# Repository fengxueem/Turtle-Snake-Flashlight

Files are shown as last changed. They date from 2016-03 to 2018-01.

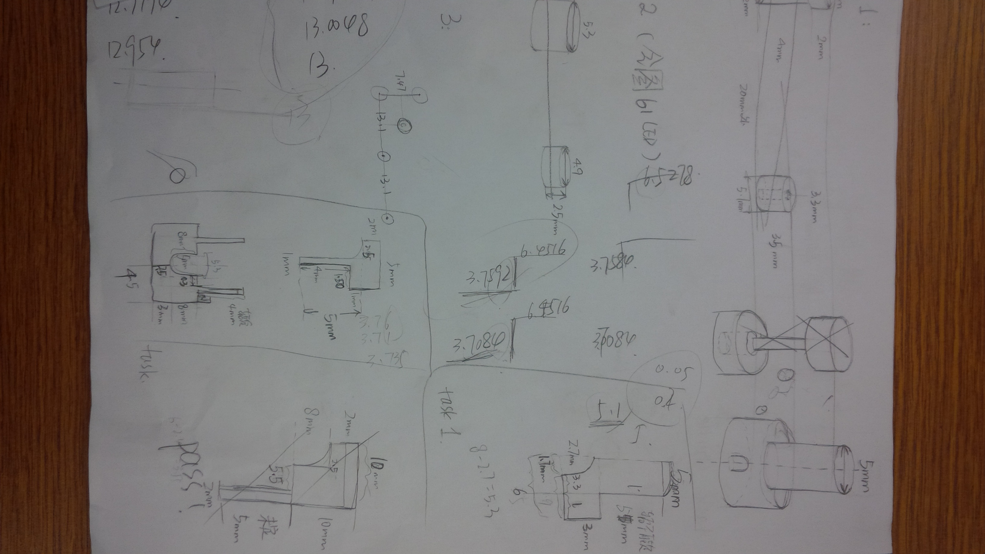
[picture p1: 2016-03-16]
Documents for EXPO2015/early sketch/Button design 2.jpg

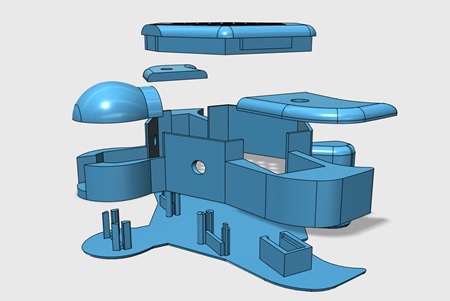
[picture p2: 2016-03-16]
Documents for EXPO2015/123dx/turtle-assemble.jpg

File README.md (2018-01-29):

# Turtle-Snake-Flashlight
This is group work as a senior design project of UIC. We created a turtle-shaped flashlight where user can play the classic "Snake Game" from stratch. This repository contains everything we've done to make it happen.
If this triggers any interests, feel free to contact me at fengxueem@sina.com

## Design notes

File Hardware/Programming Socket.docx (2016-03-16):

Programming Socket

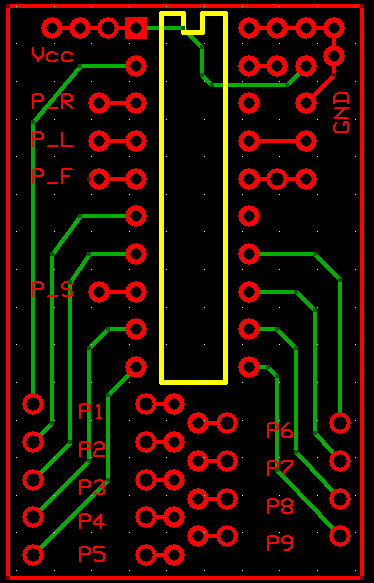
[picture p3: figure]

Programming socket

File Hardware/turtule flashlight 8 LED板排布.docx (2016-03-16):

FlaLED

FlaLED

FlaLED

FlaLED

100

100

100

Vcc

GND

100

C B E

10k

GND

10k

FlaLED

GND

C B E

FlaLED

100

100

FlaLED

FlaLED

100

100

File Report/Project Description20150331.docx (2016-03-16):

Date: 03/31/2015

Senior design project: turtle

Theme: summary on the progress so far

1. Programmable Flashlight: we decided to use hexagon as main body at very beginning which is also the shape of upper shell of the turtle. Hence, our idea changes from hexagon to make a turtle. As an extra feature for this flashlight is asked and we have a large body filled with LEDs which is perfectly for a game screen, we embed the famous and classic "Snake Game" inside.
2. Flashlight LED: The basic function of our product is flashlight. Hence, we put 8 small LEDs in the front of turtle head to illuminate everything ahead as a normal flashlight does. All the flashlights are driven by the battery with a transistor working as their switch that is controlled by an output pin from MSP430G2452.
3. Main body LED matrix: Though the screen made of LEDs is an interesting idea, it's hard for micro-controller to drive large number of LEDs and give each of them coordinates. With the help of our instructor, Vladimir Goncharoff, we use a technique invented by Charlie Allen in 1995, Charlieplexing, to drive 61 LEDs only using 9 I/O pins of MSP4302452 (this micro-controller is assigned by Dr.Goncharoff).When using Charlieplexing, n drive pins can drive A_n^2 =n^2 −n LEDs with every two pins connecting two LEDs forward and reverse.

Thus 9 pins are able to control 72 LEDs, and we only make use of 61 LEDs of total 72 possible LEDs arranged in shape of hexagon consisting of 9 columns and 9 lines. If we need to light one specific LED, the only thing we need to do is output a high voltage at its anode and low voltage at cathode, which is assigned with coordinates we designed especially for this hexagon matrix.

4. User interface: This flashlight has 4 buttons. Three of them are used for snake game and the rest one is for flashlight. The game buttons are: left button (make the snake turn left), right button (make the snake turn right) and game power switch (On/Off). The flashlight button turns 8 flashlight LEDs on and off. Normally, the voltage of all four buttons is high pulled up the built-in pull-up resistors. Once the voltage is detected to be low, it means the button is pressed.
5. Snake game: Here is the procedure of our snake game. After player pressing the game power switch, the game will start. A warm-up phase will be the first step to give player enough preparing time. During this phase, the outermost LEDs on the LED matrix will be lighted one by one with a fixed starting LED and the same one as ending LED. When the warm-up phase is finished, a snake and the first target will be shown at the LED matrix with random position and won't move until player presses the left or right button. Now the game officially begins, the snake will follow the direction given by player pressing different button. Once the snake gets a target, the speed of snake will increases and one new target will show up still randomly. As the player gets more and more targets, the speed will increase but won't go beyond a limitation. The game will end only in two situations: 1. the player presses the game power switch to shut it down; 2. the snake hits one of the six edges of our hexagon LED matrix. A feedback of how many targets this player gets will be displayed by means of a snake running from the top LED along the outermost circle to some point which is determined by player's score. The higher score the player gets, the longer the snake runs at feedback. And the player can choose to show his score to other people if he/she doesn't press left or right button after the feedback. If he/she presses, whole game will restart and run from the warm-up phase again.
6. Appearance: The turtle is made up with 6 3D-printed pieces: one top hexagon LED screen case (TOP), one middle supporting body (MID), one bottom base (BAS), two turtle libs (LIB) and one turtle head (HED). Two LIB and one HED are glued on the top surface of the MID. TOP is inserted into MID. And BAS is glued on the bottom surface of the MID.

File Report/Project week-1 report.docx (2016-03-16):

Project Week 1 Report

Group: 2B

(1). Description of the game

We designed a game named “catching star” based on the LEDs. We designed 4 buttons for the product. One is “on/off” button used for turning on and off the game. One is “reset” button used to restarting the game. “Left” and “right” buttons are used for changing the forwarding direction of the snake to left or right in 60 degrees.

After you pressing the “on/off” button, the game will start. You will have a warm-up time. During this period, the LED at the center will light in blue; meanwhile, the lights on the periphery will be lighted one by one with a random starting point. When the circle lighting finished, the end three LEDs will be the snake with the last lighted LED as the head of the snake. The LED at the center would be turned off. And a random LED on the plane will be lighted as the target “star”.

The snake will move forward automatically, you can change the direction of the snake with the “left” and “right” buttons. When you press the “left” (“right”) button, the snake will turn left (right) in 60 degrees. Each time the snake caught a star, another LED will be lighted as the target star and the moving speed of the snake would be increased.

When the speed of the snake is up to a specific value, the snake will move with the specific value. When the snake has caught 20 stars, the difficulty level of the game will be increased. The snake will disappear for one second randomly; you have to control the snake with the memory of the position and the speed of the snake. The LED at the center will be lighted in yellow for 3 seconds in random to be a barrier, if the snake hit the yellow LED, game over; if the snake strike into the periphery wall, game over.

If the snake caught 50 stars, you win the game, the central LED will be lighted in the green; if the snake hit the central barrier or the periphery wall, you loss, the central LED will be lighted in red. You can press “reset” to restart the game or “on/off” to stop playing.

(2).Required elements

element | capacitance | Red LED | RGB LED | wire | R(10K) | R | switch
number | 1 | 70(60+10) | 1 | several | 8(6+2) | 11(10+1) | 4

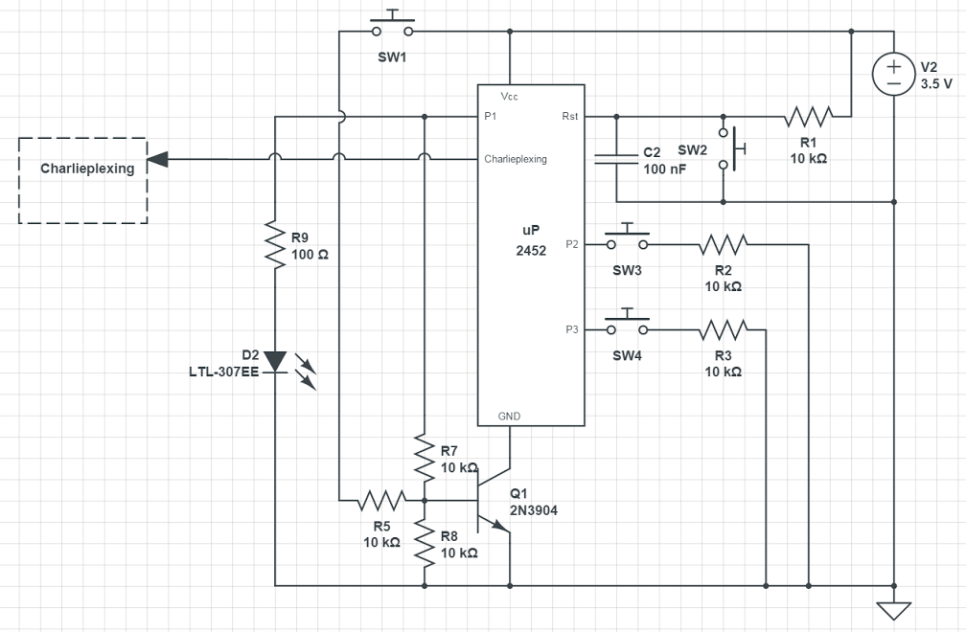
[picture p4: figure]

(3). Circuit

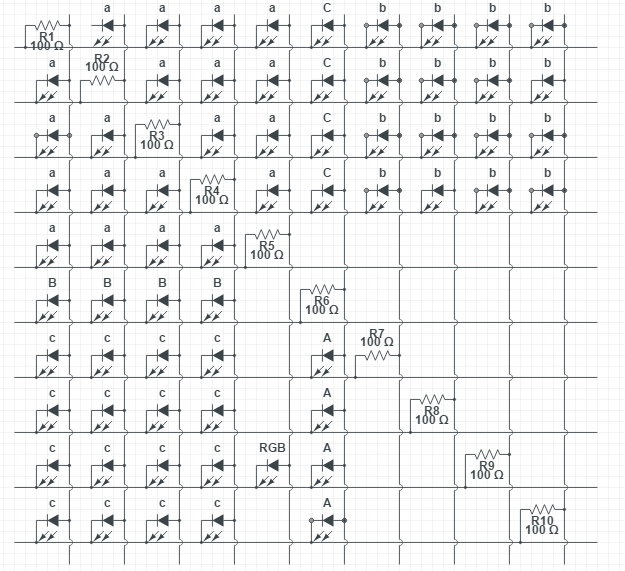
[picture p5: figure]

Charlieplexing circuit

Overall circuit

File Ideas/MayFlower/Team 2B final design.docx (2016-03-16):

Team 2B final design: MayFlower

Our design is a snowflake like flash LED.

- 1. Our product is designed as the shape of regular hexagon. And the hexagon plate is covered with single-color LEDs with one multi-color LED in the center of the hexagon. The “bling bling mode” is designed for decoration. When specific LEDs are lightened, we can get different shapes like snowflakes, sun, umbrella, lightening, characters and so on.

Mode1: different snowflakes will be lightened one by one as a circle.

# Mode2: LEDs could light in 26 characters, different characters are lighted in different order to compose some words like “hi” ”welcome”.

Mode 3: “weather flag”. Choose different weather flags to inform other people about the weather. For example, choose “sun” shinning mode, it means that it’s a sunny today. At the same time, the multi-color LED can light in different colors to mention the temperature. If it’s hot, it will light in red.

- 2. As there are lots of LEDs laying on the hexagon and our design is portable, another function of MayFlower is designed to be "Code Model". We use our LEDs to express some important signals. For instance, we can express SOS by lighting our LEDs three times for 1 second and three times for 0.5 seconds.
- 3. The LEDs can light similar to the appearance of clock. LEDs at the edge of hexagon will light one by one(per second) until LEDs of the first round of hexagon all lighted(per min) Then the second round will lit the same way as first round .This step will keep going if there is still some LEDs unlighted. Once all LEDs are lighted, they will go out together and run the steps above again as a cycle.
- 4. As the regular hexagon is centrosymmetric, we find that our MayFlower can take advantage of this physical property to rotate around the central axis. We can imagine that a rotating LED flashlight is definitely much more attractive than an immobile LED light. To accomplish this idea, we decide to make a smooth hollow rod to be assembled at the center as the rotating axis so that it will not only rotate but also can be easily attached to the wall or some other surface through the hollow part.

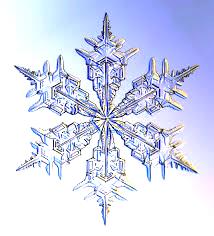
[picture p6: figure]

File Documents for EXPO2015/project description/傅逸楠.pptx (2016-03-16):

## Turtle Snake Flashlight

A teamwork project by JLU&UIC program students:
Jing Li, Chengzhang Li, Bolin Dai and Yinan Fu

Outer case

Reporter: Yinan Fu

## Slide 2

Road map

Project Requirement

Project Vision

Product Presentation

Hardware Design

Outer case Design

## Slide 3

Road map

Project Requirement

Project Vision

Product Presentation

Hardware Design

Outer case Design

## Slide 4

Project Requirement

Topic: Flashlight with one extra function

Limited hardware resources: Micro-controller, LED
(MSP430 from TI)
Resistance, Transistor

Must have a 3D-printed outer case

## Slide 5

Road map

Project Requirement

Project Vision

Product Presentation

Hardware Design

Outer case Design

## Our Vision: Make your flashlight your new snake game player!

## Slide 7

Road map

Project Requirement

Project Vision

Product Presentation

Hardware Design

Outer case Design

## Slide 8

Road map

Project Requirement

Project Vision

Product Presentation

Hardware Design

Outer case Design

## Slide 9

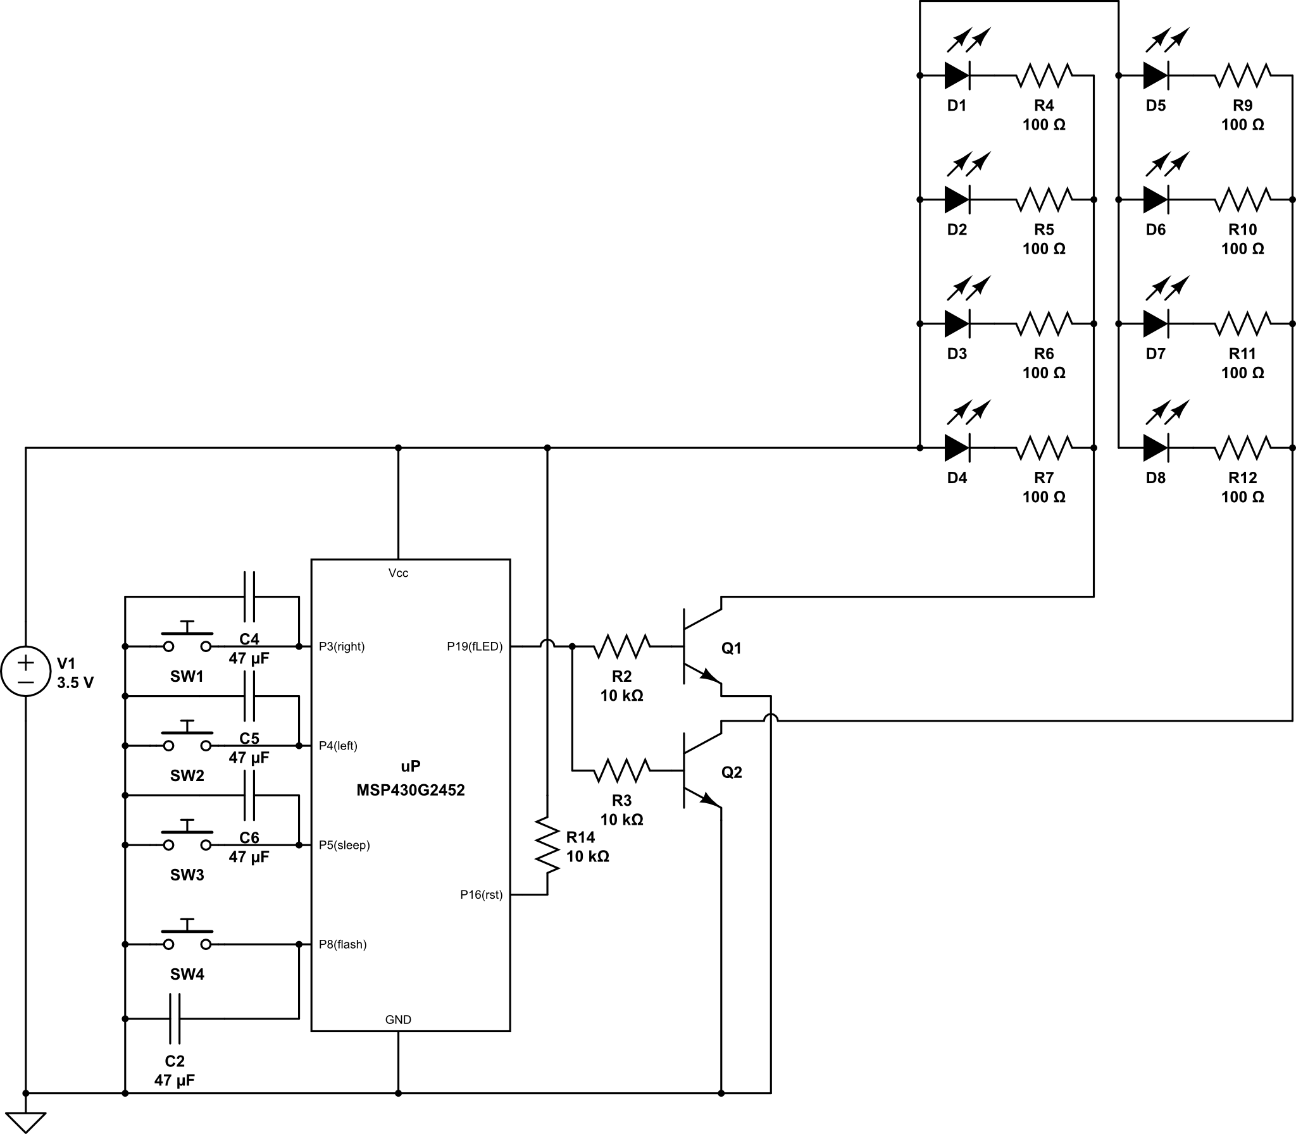
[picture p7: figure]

Main board circuit

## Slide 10

This micro-controller is powered by 3.5 voltage
given by 2 AA batteries.

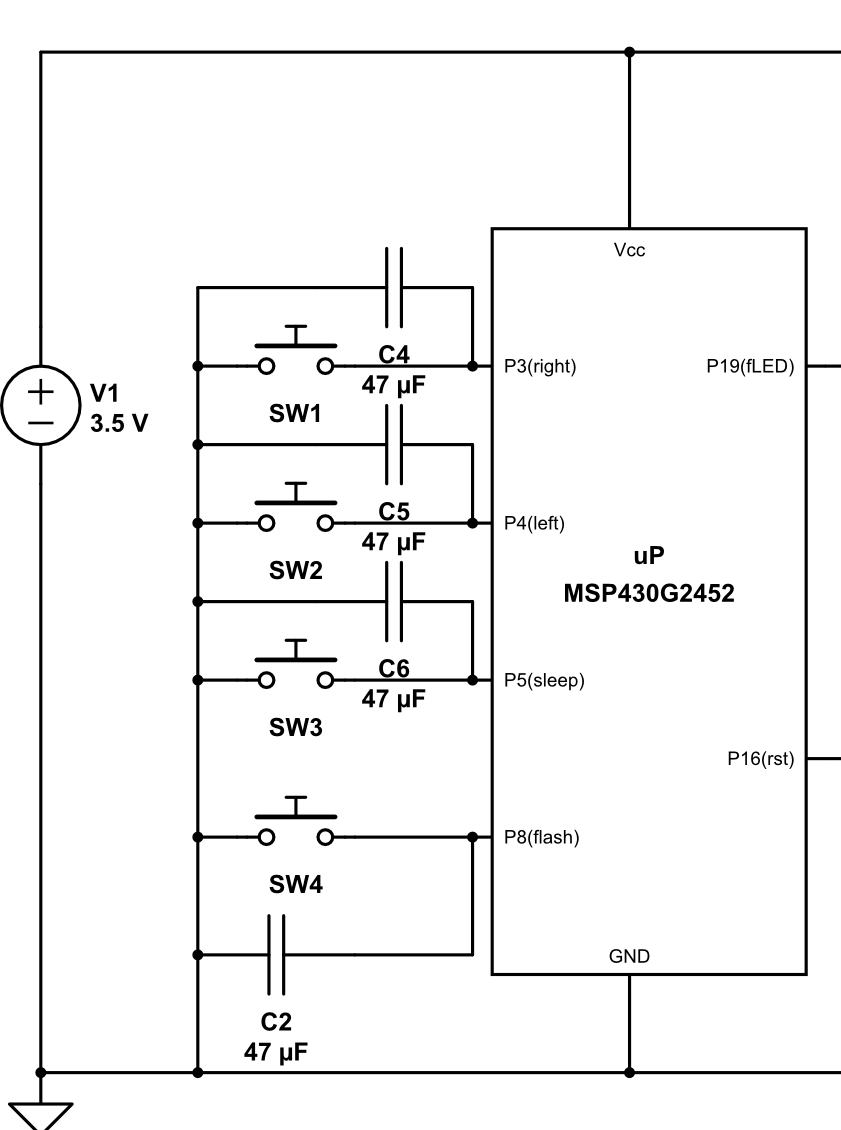
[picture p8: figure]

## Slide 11

Four switches are parallel connected with capacitance
eliminating button bounce and giving a steady press feeling.

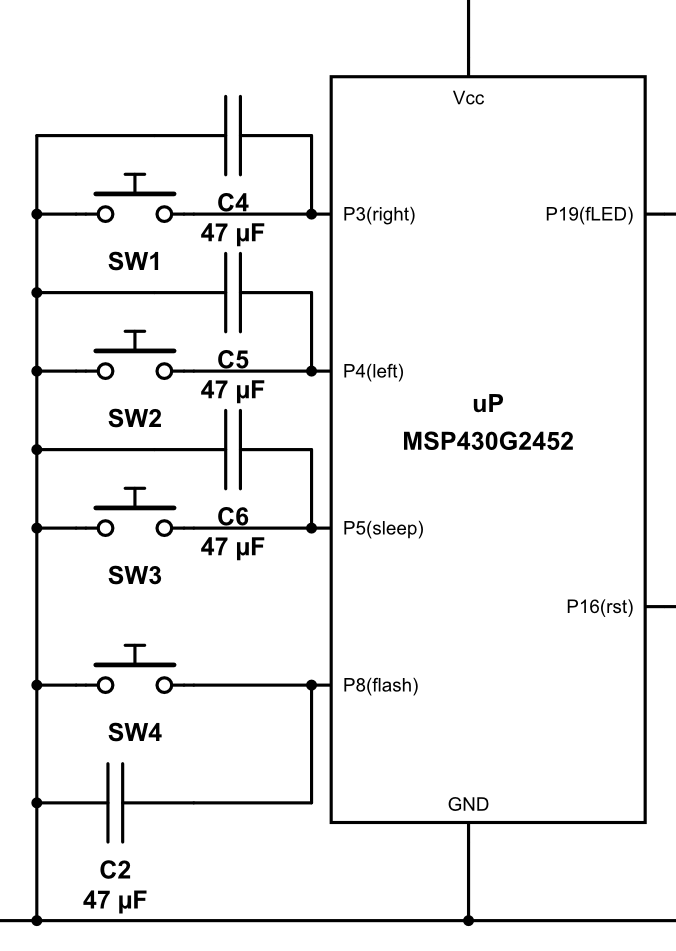
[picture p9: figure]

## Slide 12

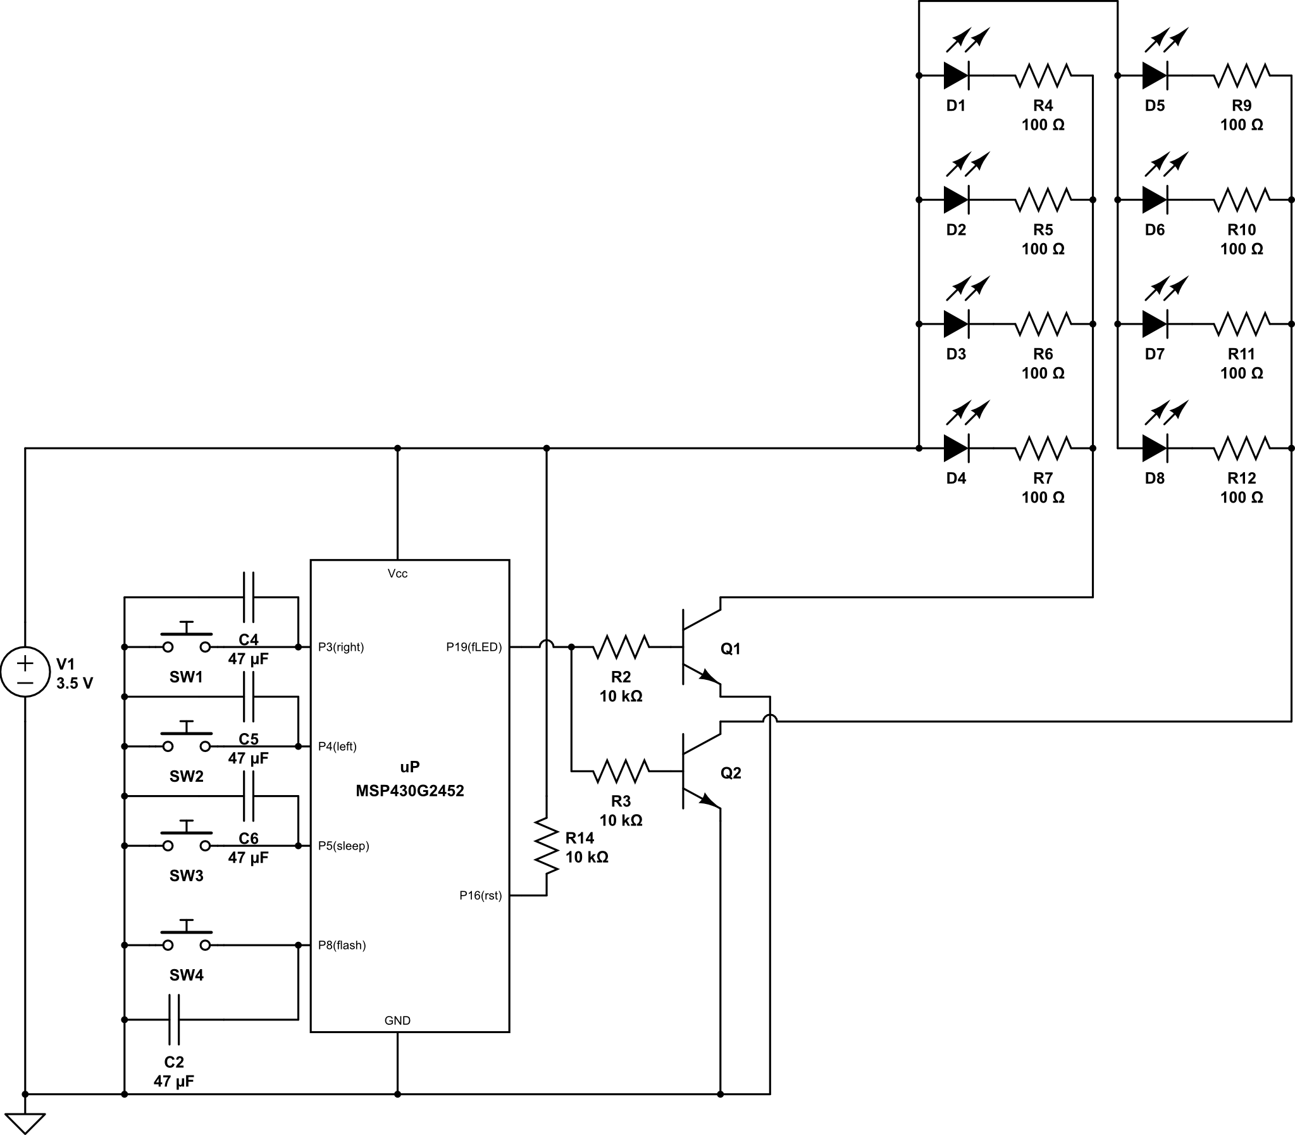
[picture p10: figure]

8 flashlight LEDs are directly driven by the battery.

One I/O pin is used to control the connectivity of these LEDs.

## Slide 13

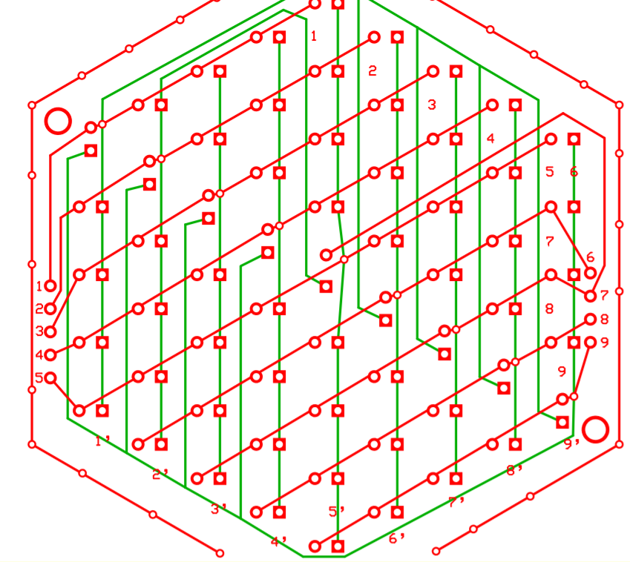
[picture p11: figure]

We use 9 I/O pins to control 61 LEDs

Main LED matrix

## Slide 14

Charlieplexing

P1

2 pins can control 2∗2−2=2 LEDs

P2

P1

P2

3 pins can control 3∗3−3=6 LEDs

P3

n pins can control n∗n−n=n^2 −n LEDs
So, 9 pins are able to have 9∗9−9=72 LEDs,
which is more than enough.

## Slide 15

Road map

Project Requirement

Project Vision

Product Presentation

Hardware Design

Outer case Design

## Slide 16

3D Printer

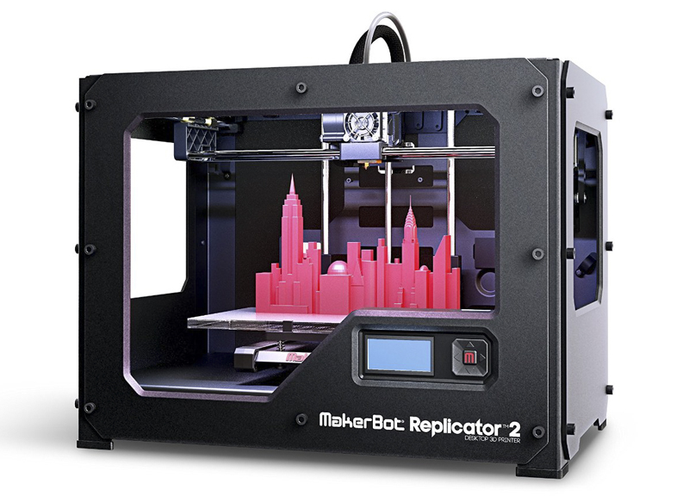
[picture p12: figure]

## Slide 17

Printing Scene

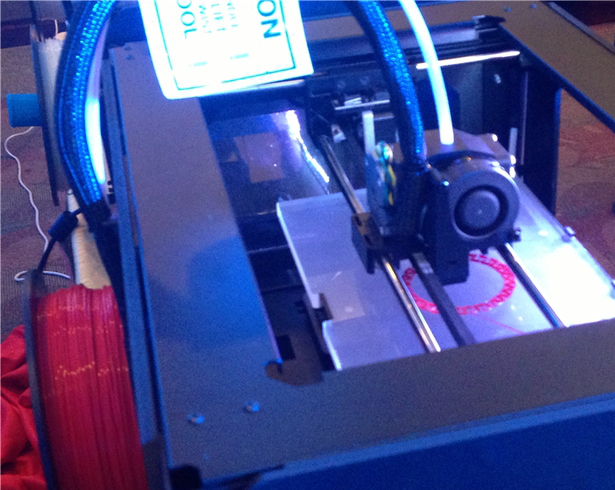
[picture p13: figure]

extruder

filament

Build plane

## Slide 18

Perspective diagram

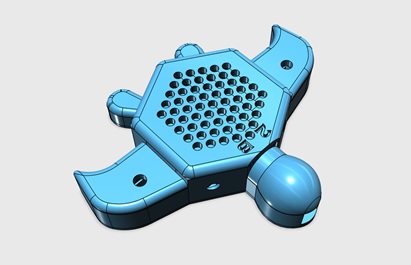
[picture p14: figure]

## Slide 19

Perspective diagram

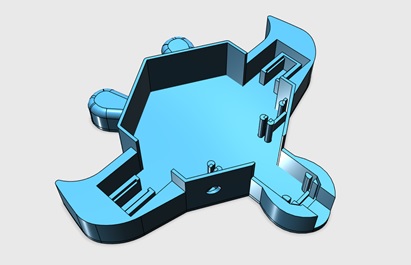
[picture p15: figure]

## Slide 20

Assembling diagram


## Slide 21

Thank You!

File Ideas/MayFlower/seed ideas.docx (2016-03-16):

Group Member: Yinan Fu; Bolin Dai; Chengzhang Li; Jing Li

Seed Ideas:

#1. We want to make the appearance of our flashlight as a revolver with the color LED inside the gun-barrel and 4 single-color LEDs located on wheel of the revolver just like the image below:

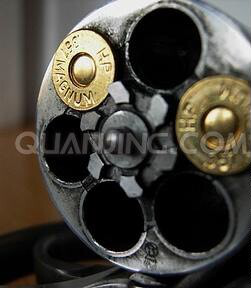
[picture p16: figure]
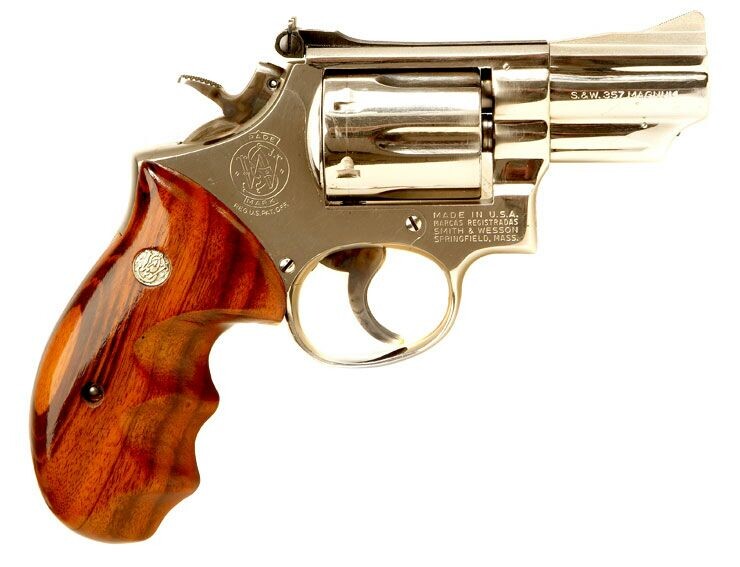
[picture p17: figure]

Single-color

LED

Color LED

#2. We design 2 special lighting models. One is SOS model: All the flashlights will flicker 6 times as a period. In the first 3 times the lights will be lighted for 0.5s and go dark each time. In the other 3 times the lights will keep on for 0.2s then go dark each time. And this lighting model will repeat again and again.

#3.Shooting Model: When you press the trigger the LED light will light once, but not the same every time you press. Normally, the light will flash once with white color. In other case the light will be bloody-red color lasting 1s just like someone being shot. Both cases will happen randomly.

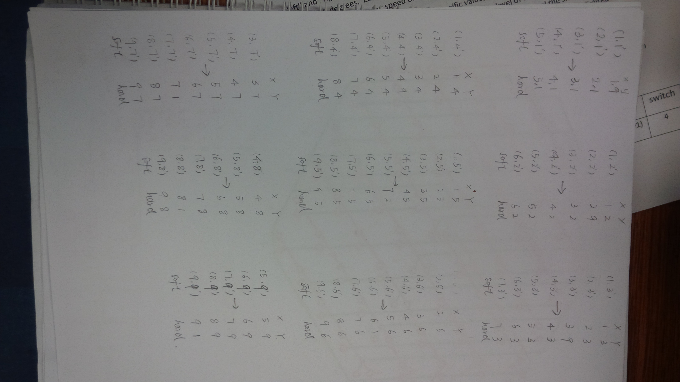
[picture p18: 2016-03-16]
Documents for EXPO2015/early sketch/Hardware LED coord. to Software LED coord.jpg

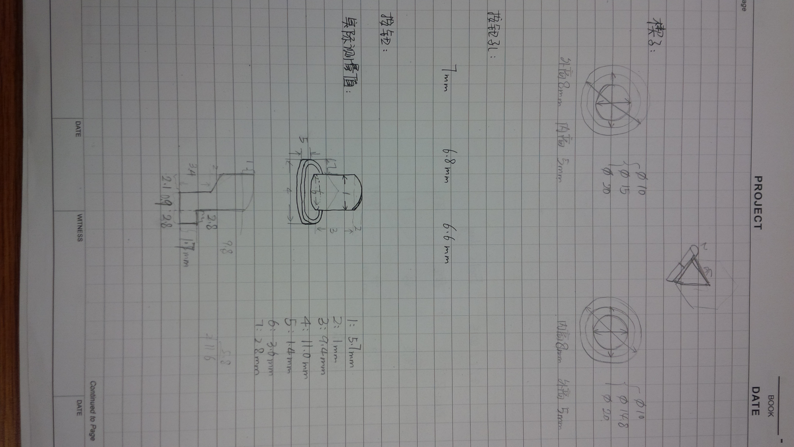
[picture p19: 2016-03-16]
Documents for EXPO2015/early sketch/Button design 1.jpg

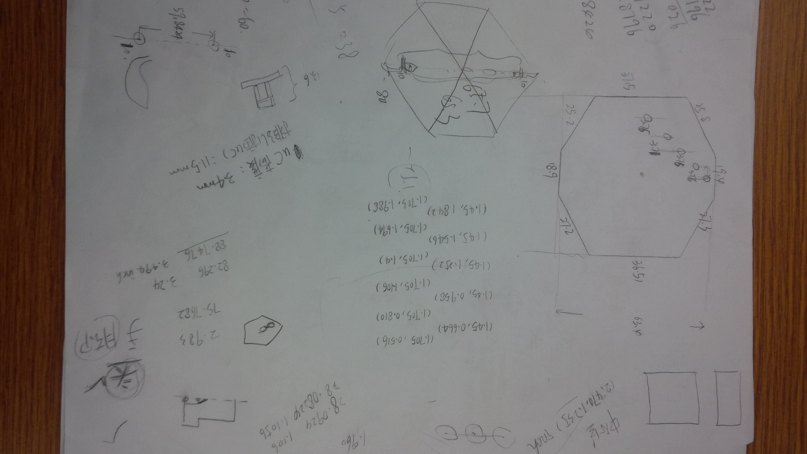
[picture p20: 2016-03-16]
Documents for EXPO2015/early sketch/Top cover design.jpg

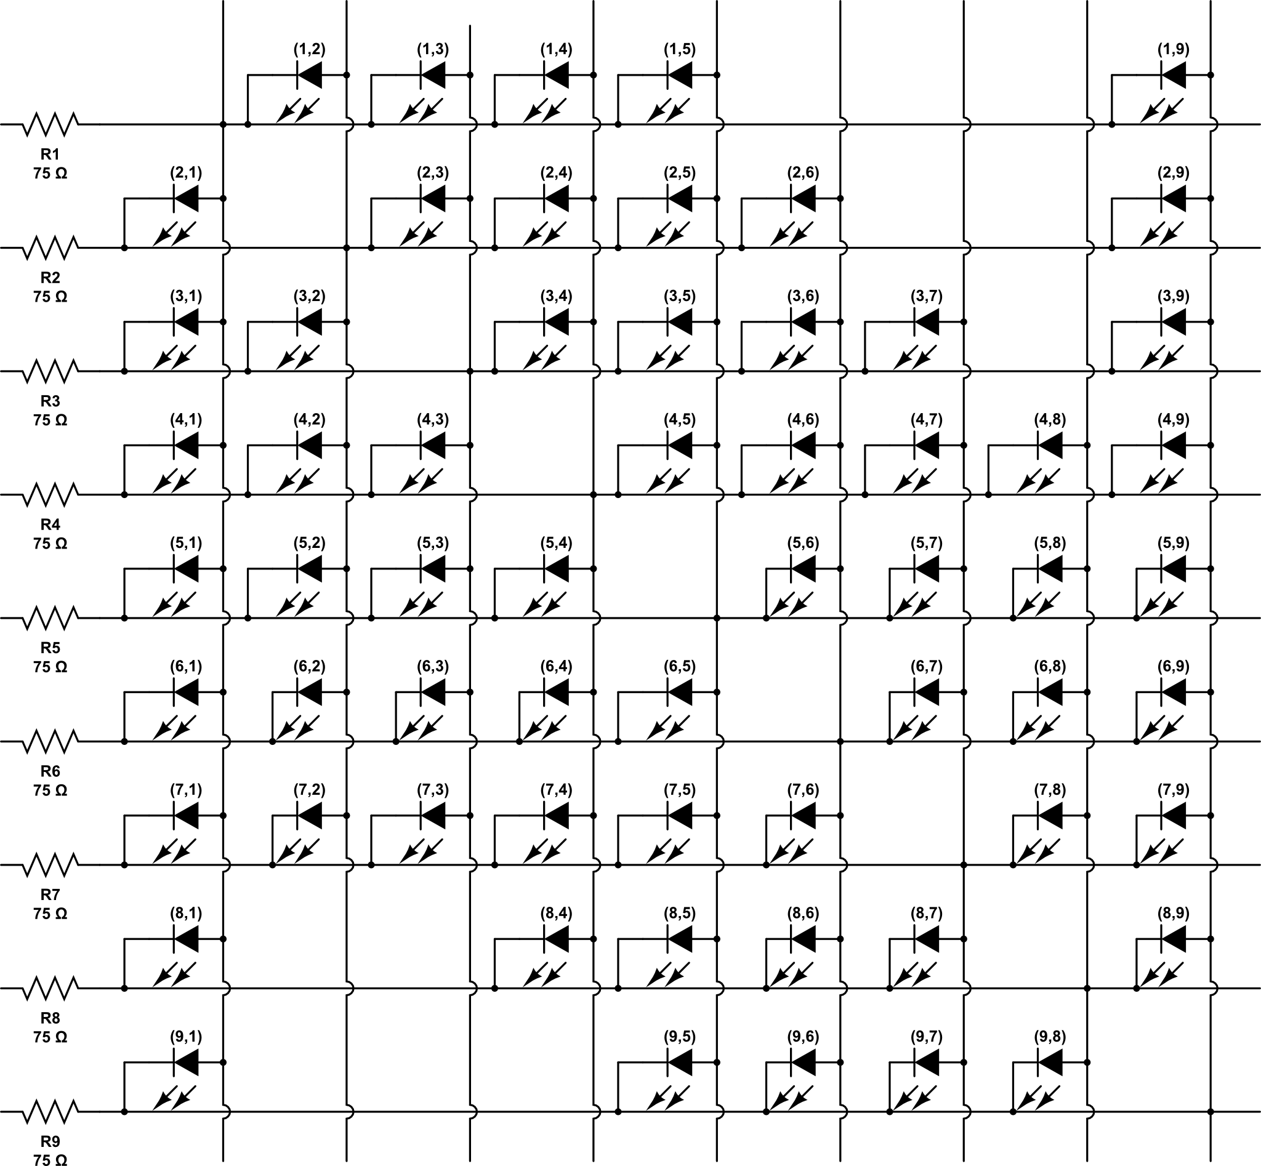
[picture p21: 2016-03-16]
Hardware/61LED_charlieplexing.png

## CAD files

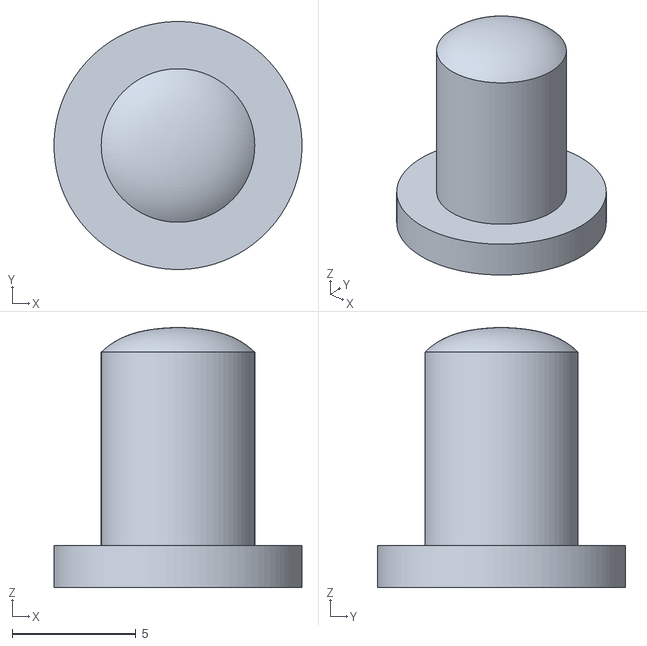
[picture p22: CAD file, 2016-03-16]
Appearance/打印的文件/button/2B-button1-dbl.stl
10.0 x 10.0 x 10.5

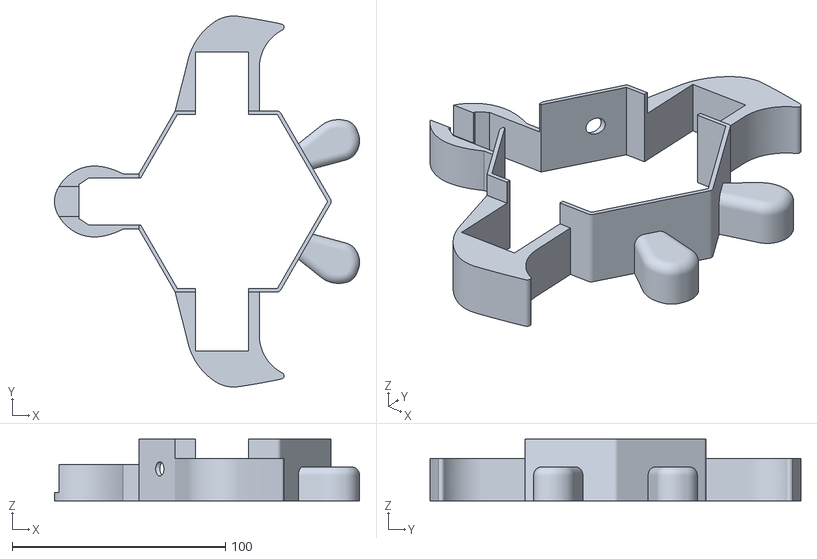
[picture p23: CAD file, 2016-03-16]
Appearance/打印的文件/mid/2B-mid v3.stl
143.1 x 174.0 x 29.0

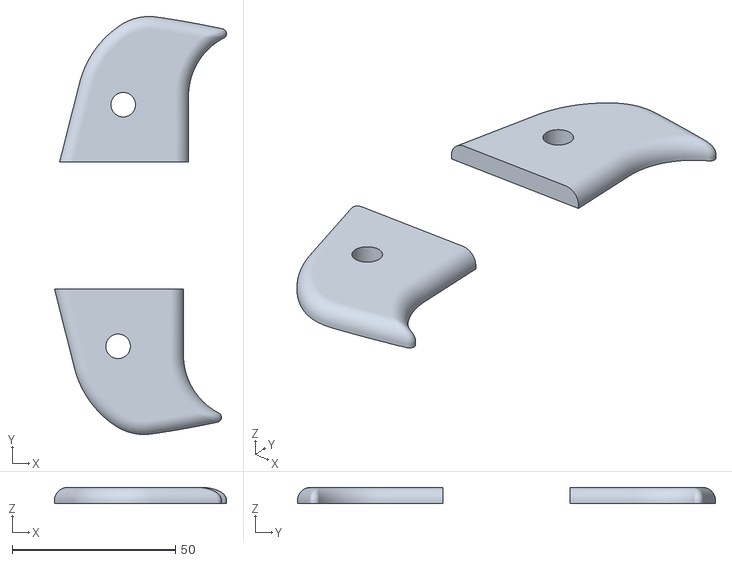
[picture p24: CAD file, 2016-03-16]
Appearance/打印的文件/wing/2B-wings.stl
52.7 x 127.9 x 5.00

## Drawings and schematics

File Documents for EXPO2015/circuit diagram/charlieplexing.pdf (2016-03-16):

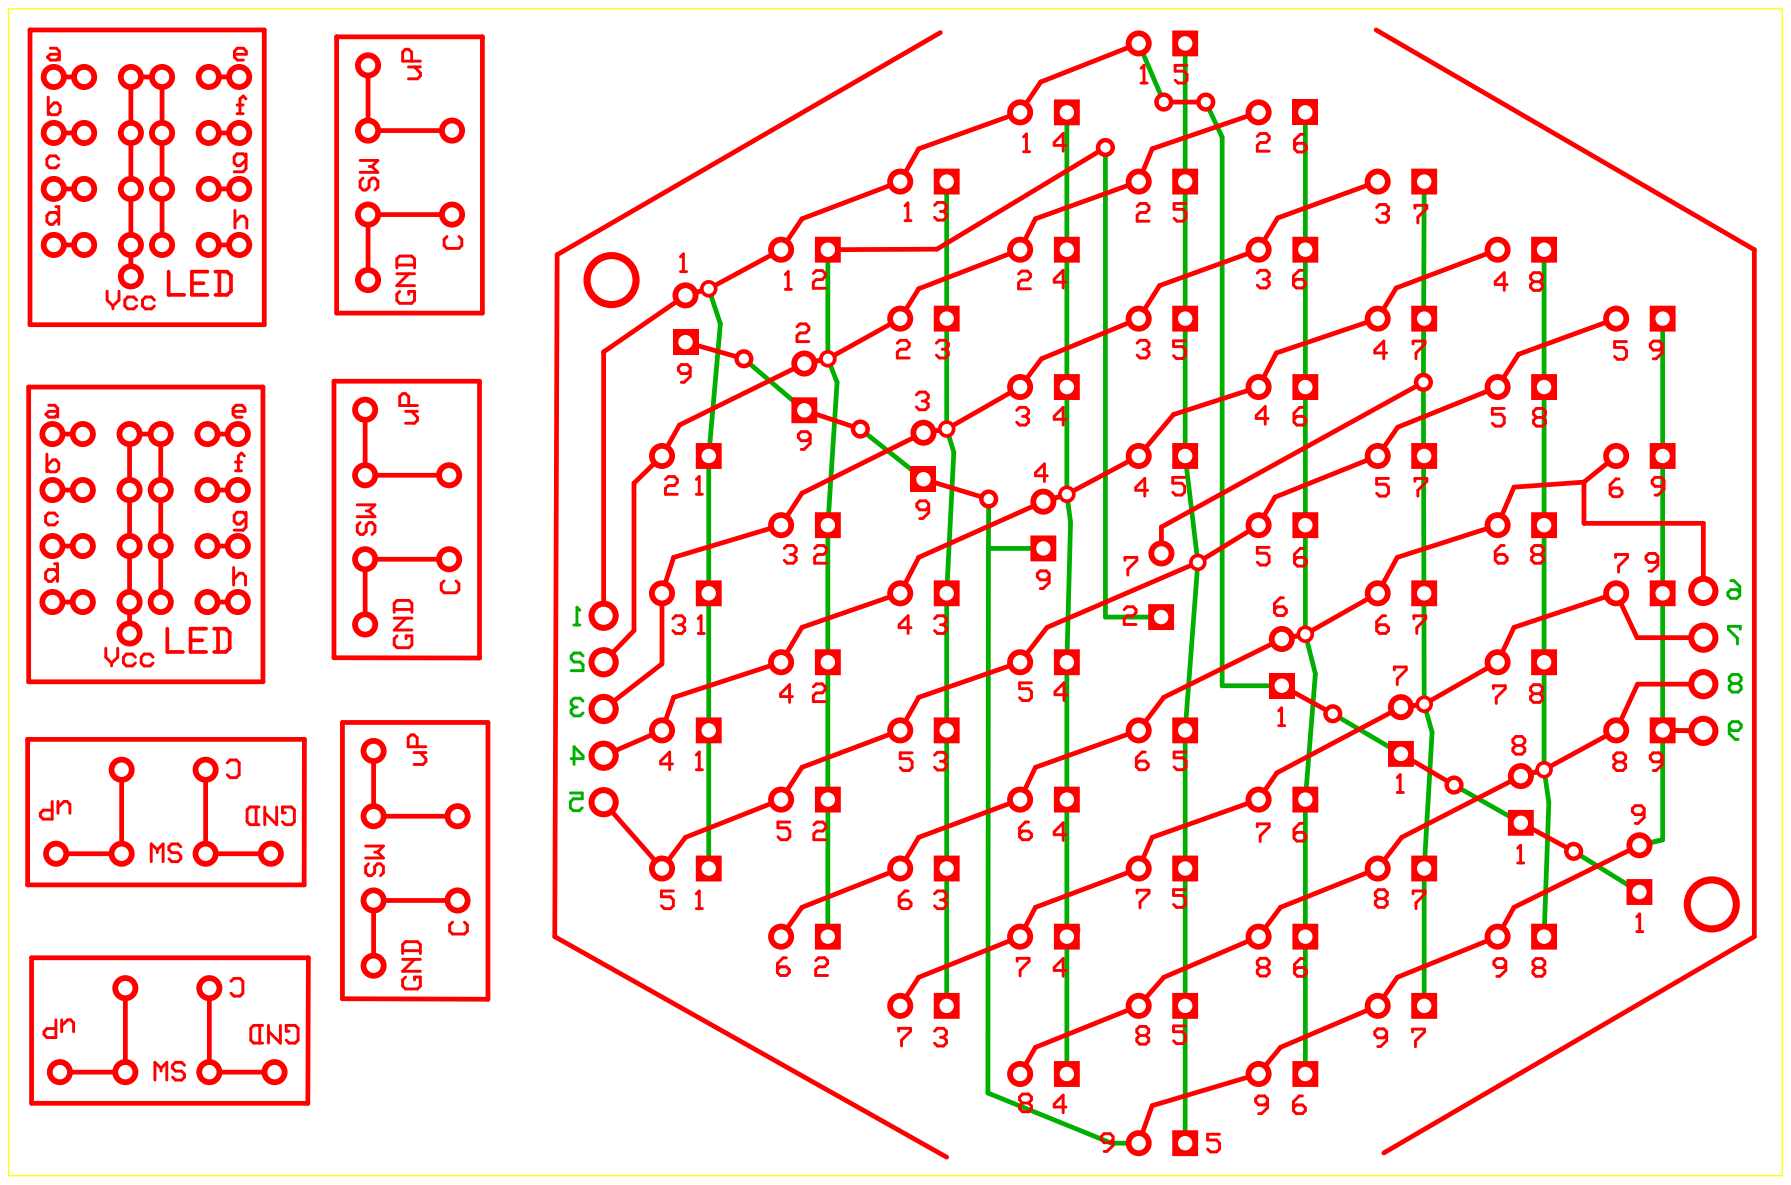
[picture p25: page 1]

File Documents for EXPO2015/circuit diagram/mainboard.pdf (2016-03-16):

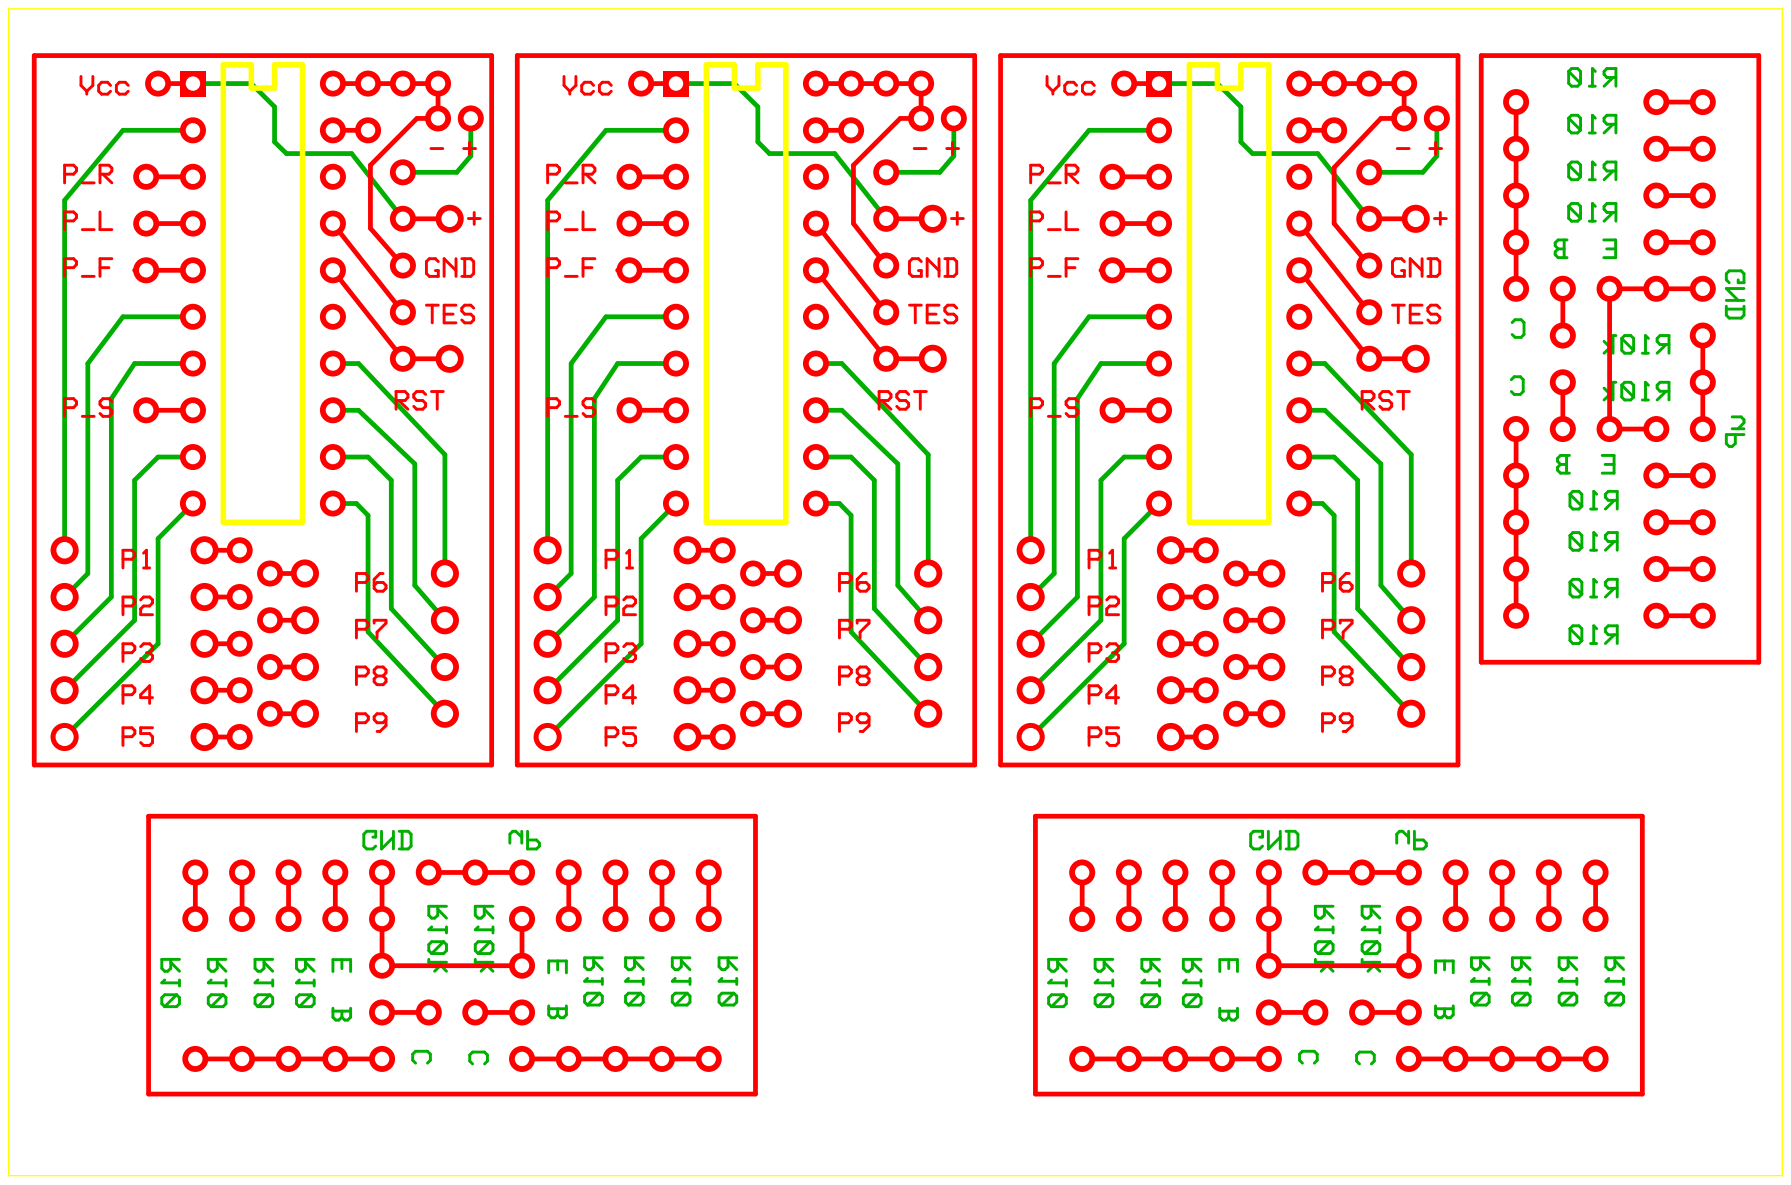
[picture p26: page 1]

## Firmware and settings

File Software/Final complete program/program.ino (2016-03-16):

#define P_L 4//the pin number of left button
#define P_R 3//the pin number of right button
#define P_sleep 5//the pin number of on/off switch
#define P_flaswch 8//the pin number of flash switch 
#define P_1 2//the pin number of 1 charlie pin
#define P_2 6//the pin number of 2 charlie pin
#define P_3 7//the pin number of 3 charlie pin
#define P_4 9//the pin number of 4 charlie pin
#define P_5 10//the pin number of 5 charlie pin
#define P_6 14//the pin number of 6 charlie pin
#define P_7 13//the pin number of 7 charlie pin
#define P_8 12//the pin number of 8 charlie pin
#define P_9 11//the pin number of 9 charlie pin
#define P_flash 19 //the pin number of flash light
#define time_one 1//time duration of one LED being lightened
#define time_warmup 80
#define begin_speed 90
#define exponentialdecrease_speed 40
#define end_speed 14
#define left (-1)// turn left	
#define right (1)// turn right
const int debounce_delay = 250;// 1/4 sec debouncing delay after sleep switch is closed or opened 
unsigned int spd,level;//snake speed and game level
unsigned int ld;
unsigned int x_1,x_2,x_3,randx,y_1,y_2,y_3,randy;
unsigned int f_flag=0;
volatile unsigned int d,L=0,R=0;//L and R record the number of how many times the left and right buttons are pressed. 
                      //d is the next direction of snake,ld is the last direction snake went from.
boolean lf,rf;
/*------For avoiding button bounce-----*/
#define NOT_PUSHED true
#define WATCH_BUTTON true
#define IGNORE_BUTTON false
const long buttonWaitInterval = 200000;
unsigned long previousMicros = 0;
boolean bounceState = false;
/*----------------------------------*/
void setup()
{
 Initialize_Pins();
 warmup();
 randsnake();
 randtarget();
 ld=d;
 lf=leftbutton();
 rf=rightbutton();
 while((lf==0)&&(rf==0))//display the snake and target
  {
      lightone(x_1,y_1,time_one);
      lightone(x_2,y_2,time_one);
      lightone(x_1,y_1,time_one);
      lightone(x_3,y_3,time_one);
      lightone(x_1,y_1,time_one);
      lightone(x_2,y_2,time_one);
      lightone(randx,randy,time_one);
      lightone(x_1,y_1,time_one);
      lightone(x_2,y_2,time_one);
      lightone(randx,randy,time_one);
      lightone(x_1,y_1,time_one);
      lf=leftbutton();
      rf=rightbutton();
      if (digitalRead(P_sleep) == LOW) Fall_Asleep();
  }
}
void loop()
{
  if(abs(L-R)>=3)//update new direction
  {
    if(L>R)   d=(6+ld-2)%6;
    else        d=(6+ld+2)%6;
  }
  L=0;R=0;ld=d;
  dir_coor();//update coordinates according the new direction
  GameOver();//determine whether it hits a wall or not
  for(int t=0;t<=spd;t++)//display the snake
  {
    if (digitalRead(P_sleep) == LOW)   Fall_Asleep();
    lf=leftbutton();
    rf=rightbutton();
    lightone(x_1,y_1,time_one);
    lightone(x_2,y_2,time_one);
    lightone(x_1,y_1,time_one);
    lightone(x_3,y_3,time_one);
    lightone(x_1,y_1,time_one);
    lightone(x_2,y_2,time_one);
    lightone(randx,randy,time_one);
    lightone(x_1,y_1,time_one);
    lightone(x_2,y_2,time_one);
    lightone(randx,randy,time_one);
    lightone(x_1,y_1,time_one);
  }
  judgement();//determine whether it gets the target or not
}

void Fall_Asleep(void) 
{
  delay(debounce_delay);     // delay for approximately 250ms, longer than duration of switch bounce
  // Put all I/O pins into input mode to save power when uC goes to sleep:
  pinMode(2,INPUT);
  pinMode(3,INPUT);
  pinMode(4,INPUT);
  pinMode(P_sleep,INPUT_PULLUP);   // pullup resistor for switch that will interrupt sleep mode
  pinMode(6,INPUT);
  pinMode(7,INPUT);
  pinMode(P_flaswch,INPUT_PULLUP);
  pinMode(9,INPUT);
  pinMode(10,INPUT);
  pinMode(11,INPUT);
  pinMode(12,INPUT);
  pinMode(13,INPUT);
  pinMode(14,INPUT);
  pinMode(15,INPUT);
  // Enable interrupt upon HIGH to LOW transition at pin 5 (P1.3, S2 on LaunchPad board)
  P1IE |= BIT3;              // Enable interrupt by change in voltage at pin P1.3
  P1IES |= BIT3;             // Specifically, trigger interrupt at HIGH to LOW transition in P1.3
  P1IFG &= ~BIT3;            // Clear interrupt flage IFG corresponding to pin P1.3
  // fall asleep:
  _BIS_SR(LPM4_bits + GIE);  // Enter Low Power Mode 4 w/interrupt
  // upon waking up:
  delay(debounce_delay);           // delay for approximately 250ms, longer than duration of switch bounce
  Initialize_Pins();                  // Initialize I/O pins after sleep mode
  warmup();
  randsnake();
  randtarget();
  ld=d;
  lf=leftbutton();
  rf=rightbutton();
  while((lf==0)&&(rf==0))//display the snake and target
   {
       lightone(x_1,y_1,time_one);
       lightone(x_2,y_2,time_one);
       lightone(x_1,y_1,time_one);
       lightone(x_3,y_3,time_one);
       lightone(x_1,y_1,time_one);
       lightone(x_2,y_2,time_one);
       lightone(randx,randy,time_one);
       lightone(x_1,y_1,time_one);
       lightone(x_2,y_2,time_one);
       lightone(randx,randy,time_one);
       lightone(x_1,y_1,time_one);
       lf=leftbutton();
       rf=rightbutton();
       if (digitalRead(P_sleep) == LOW) Fall_Asleep();
   }
}

void Initialize_Pins(void)
{
  pinMode(P_1,INPUT);//charlieplexing output pins,from 1 to 9
  pinMode(P_2,INPUT);
  pinMode(P_3,INPUT);
  pinMode(P_4,INPUT);
  pinMode(P_5,INPUT);
  pinMode(P_6,INPUT);
  pinMode(P_7,INPUT);
  pinMode(P_8,INPUT);
  pinMode(P_9,INPUT);
  pinMode(P_flash,OUTPUT);//flashlight transistor pin
  pinMode(P_sleep,INPUT_PULLUP);//P1.3
  pinMode(P_flaswch,INPUT_PULLUP);//P2.0
  pinMode(P_L,INPUT_PULLUP);//P1.2
  pinMode(P_R,INPUT_PULLUP);//P1.1
  P2IE |= BIT0;              // Enable interrupt by change in voltage at pin P2.0( P_flaswch)
  P2IES |= BIT0;             // Specifically, trigger interrupt at HIGH to LOW transition in P2.0( P_flaswch)
  P2IFG &= ~BIT0;            // Clear interrupt flage IFG corresponding to pin P2.0( P_flaswch)
  L=0;R=0;spd=begin_speed;level=0;
  srand((unsigned)millis());//update new time seed
}

void turn(int dir)
{
  d=(6+d+dir)%6;
} 

void warmup(void)
{
  x_1=1;
  y_1=5;
  d=2;
  for(int i=1;i<=25;i++)
  {
    lightone(x_1,y_1,time_warmup);
    lightone(x_1,y_1,time_warmup);
    dir_coor();
    if(i%4==0) turn(right);
    if (digitalRead(P_sleep) == LOW)   Fall_Asleep();
  }
}

void randsnake(void)
{
  do
  {
	x_1=(abs(rand())%5)+3;
        y_1=(abs(rand())%5)+3;
  }while(abs(x_1-y_1)>=3);//control the area where the snake's head  first shows up into central haxegon with side length equal to 3 leds
  d=abs(rand())%6;
  ld=d;
  switch(ld)
  {
    case 0:x_2=x_1+1;y_2=y_1;x_3=x_2+1;y_3=y_2;break;
    case 1:x_2=x_1;y_2=y_1-1;x_3=x_2;y_3=y_2-1;break;
    case 2:x_2=x_1-1;y_2=y_1-1;x_3=x_2-1;y_3=y_2-1;break;
    case 3:x_2=x_1-1;y_2=y_1;x_3=x_2-1;y_3=y_2;break;
    case 4:x_2=x_1;y_2=y_1+1;x_3=x_2;y_3=y_2+1;break;
    case 5:x_2=x_1+1;y_2=y_1+1;x_3=x_2+1;y_3=y_2+1;break;
  }
}

void randtarget(void)
{
  do
  {
	  randx=(abs(rand())%9)+1;
	  randy=(abs(rand())%9)+1;
  }while((abs(randx-randy)>=5)||((randx==x_1)&&(randy==y_1))||((randx==x_2)&&(randy==y_2))||((randx==x_3)&&(randy==y_3)));
}

void judgement(void)
{
  if((x_1==randx)&&(y_1==randy))  
  {
    randtarget();level++;
    if(spd>exponentialdecrease_speed) spd=spd-(int)sqrt(spd);
    else if(spd>=end_speed) spd--;
  }
}

void dir_coor(void)
{ 
   ld=d;
   switch(ld)
   {
     case 0:x_3=x_2;y_3=y_2;x_2=x_1;y_2=y_1;x_1=x_1-1;break;//y_1 stays the same
     case 1:x_3=x_2;y_3=y_2;x_2=x_1;y_2=y_1;y_1=y_1+1;break;//x_1 stays the same
     case 2:x_3=x_2;y_3=y_2;x_2=x_1;y_2=y_1;x_1=x_1+1;y_1=y_1+1;break;
     case 3:x_3=x_2;y_3=y_2;x_2=x_1;y_2=y_1;x_1=x_1+1;break;//y_1 stays the same
     case 4:x_3=x_2;y_3=y_2;x_2=x_1;y_2=y_1;y_1=y_1-1;break;//x_1 stays the same
     case 5:x_3=x_2;y_3=y_2;x_2=x_1;y_2=y_1;x_1=x_1-1;y_1=y_1-1;break;
   }
}

void GameOver(void)
{
  if((x_1<1)||(x_1>9)||(y_1<1)||(y_1>9)||((x_1==1)&&(y_1==6))||((x_1==2)&&(y_1==7))||((x_1==3)&&(y_1==8))||((x_1==4)&&(y_1==9))||((x_1==9)&&(y_1==4))||((x_1==8)&&(y_1==3))||((x_1==7)&&(y_1==2))||((x_1==6)&&(y_1==1)))
  { //game over
     unsigned  int x_4=0,y_4=0;//recover the last location of tail
     switch(ld)
	  {
	  case 0:x_4=x_3+1;y_4=y_3;break;
	  case 1:x_4=x_3;y_4=y_3-1;break;
	  case 2:x_4=x_3-1;y_4=y_3-1;break;
	  case 3:x_4=x_3-1;y_4=y_3;break;
	  case 4:x_4=x_3;y_4=y_3+1;break;
	  case 5:x_4=x_3+1;y_4=y_3+1;break;
	  }
     for(int j=0;j<=2;j++)
       {
         for(int i=0;i<=50;i++)
         {
           lightone(x_2,y_2,time_one);//head
           lightone(x_3,y_3,time_one);//body
           lightone(x_4,y_4,time_one);//tail
         }
         delay(500);
       }
      showscore();
      Initialize_Pins();
      warmup();
      randsnake();
      randtarget();
      ld=d;
      lf=leftbutton();
      rf=rightbutton();
      while((lf==0)&&(rf==0))//display the snake and target
      {
          if (digitalRead(P_sleep) == LOW) Fall_Asleep();
          lightone(x_1,y_1,time_one);
          lightone(x_2,y_2,time_one);
          lightone(x_1,y_1,time_one);
          lightone(x_3,y_3,time_one);
          lightone(x_1,y_1,time_one);
          lightone(x_2,y_2,time_one);
          lightone(randx,randy,time_one);
          lightone(x_1,y_1,time_one);
          lightone(x_2,y_2,time_one);
          lightone(randx,randy,time_one);
          lightone(x_1,y_1,time_one);
          lf=leftbutton();
          rf=rightbutton();
      }
  }
}

void showscore(void)
{
   x_1=1;
   y_1=5;
   d=2;
   ld=d;
   switch(ld)
   {
     case 0:x_2=x_1+1;y_2=y_1;x_3=x_2+1;y_3=y_2;break;
     case 1:x_2=x_1;y_2=y_1-1;x_3=x_2;y_3=y_2-1;break;
     case 2:x_2=x_1-1;y_2=y_1-1;x_3=x_2-1;y_3=y_2-1;break;
     case 3:x_2=x_1-1;y_2=y_1;x_3=x_2-1;y_3=y_2;break;
     case 4:x_2=x_1;y_2=y_1+1;x_3=x_2;y_3=y_2+1;break;
     case 5:x_2=x_1+1;y_2=y_1+1;x_3=x_2+1;y_3=y_2+1;break;
   }
   for(int m=1;m<((level+1)/2)+1;m++)
   {
     for(int p=0;p<=(3*end_speed);p++)
     {
       lightone(x_1,y_1,time_one);
       lightone(x_2,y_2,time_one);
       lightone(x_3,y_3,time_one);
     }
     if (m==(level+1)/2)
     {
       lf=leftbutton();
       rf=rightbutton();
       while((lf==0)&&(rf==0))
       {
         if (digitalRead(P_sleep) == LOW) Fall_Asleep();
         lightone(x_1,y_1,time_one);
         lightone(x_2,y_2,time_one);
         lightone(x_3,y_3,time_one);
         lf=leftbutton();
         rf=rightbutton();
       }
     }
     dir_coor();
     if(m%4==0) turn(right);
   }
}

void lightone(int x, int y,int time) //light up one LED in very little duration to deceive th eyes
{
  int pinx,piny;
  if(x!=y)
  {
    pinx=codtopin(x);piny=codtopin(y);
    pinMode(pinx,OUTPUT);
    pinMode(piny,OUTPUT);
    digitalWrite(pinx,HIGH);
    digitalWrite(piny,LOW);
    delay(time);
    pinMode(pinx,INPUT);
    pinMode(piny,INPUT);
  }
  else
  {
    if(x<=4)
    {
      pinx=codtopin(x);
      pinMode(pinx,OUTPUT);
      pinMode(P_9,OUTPUT);
      digitalWrite(pinx,HIGH);
      digitalWrite(P_9,LOW);
      delay(time);
      pinMode(pinx,INPUT);
      pinMode(P_9,INPUT);
    }
    else if(x==5)
    {
      pinMode(P_7,OUTPUT);
      pinMode(P_2,OUTPUT);
      digitalWrite(P_7,HIGH);
      digitalWrite(P_2,LOW);
      delay(time);
      pinMode(P_7,INPUT);
      pinMode(P_2,INPUT);
    }
    else
    {
      pinx=codtopin(x);
      pinMode(pinx,OUTPUT);
      pinMode(P_1,OUTPUT);
      digitalWrite(pinx,HIGH);
      digitalWrite(P_1,LOW);
      delay(time);
      pinMode(pinx,INPUT);
      pinMode(P_1,INPUT);      
    }
  }     
}

int codtopin(int x)
{
int X;
switch(x)
{
    case 1:X=P_1;break;
    case 2:X=P_2;break;
    case 3:X=P_3;break;
    case 4:X=P_4;break;
    case 5:X=P_5;break;
    case 6:X=P_6;break;
    case 7:X=P_7;break;
    case 8:X=P_8;break;
    case 9:X=P_9;break;
  }
  return X;
}
 
#pragma vector=PORT1_VECTOR
__interrupt void Port_1(void)  
{
    __bic_SR_register_on_exit(LPM4_bits+GIE); // Resume execution in Active Mode
  P1IFG &= 0x00;
}

#pragma vector=PORT2_VECTOR
__interrupt void Port_2(void)  
{
  if(f_flag==0) {digitalWrite(P_flash,HIGH);f_flag=1;}
  else {digitalWrite(P_flash,LOW);f_flag=0;}
  P2IFG &= ~BIT0; 
}

bool leftbutton()
{
  if (bounceState == WATCH_BUTTON) 
  {
    if (digitalRead(P_L)==LOW) 
    {
      bounceState = IGNORE_BUTTON;previousMicros = micros();turn(left);L++;return(1);
    }
    else return(0);
  }
  if (bounceState == IGNORE_BUTTON) 
  {
    unsigned long currentMicros = micros();
    if ((unsigned long)(currentMicros - previousMicros) >= buttonWaitInterval) 
    {
      bounceState = WATCH_BUTTON;
    } 
  }
}

bool rightbutton()
{
  if (bounceState == WATCH_BUTTON) 
  {
    if (digitalRead(P_R)==LOW) 
    {
      bounceState = IGNORE_BUTTON;previousMicros = micros();turn(right);R++;return(1);
    }
    else return(0);
  }
  if (bounceState == IGNORE_BUTTON) 
  {
    unsigned long currentMicros = micros();
    if ((unsigned long)(currentMicros - previousMicros) >= buttonWaitInterval) 
    {
      bounceState = WATCH_BUTTON;
    } 
  }
}

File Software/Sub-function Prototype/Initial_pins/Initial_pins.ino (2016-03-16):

void Initialize_Pins(void) 
{
  pinMode(P_1,OUTPUT);//charlieplexing output pins,from 1 to 9
  pinMode(P_2,OUTPUT);
  pinMode(P_3,OUTPUT);
  pinMode(P_4,OUTPUT);
  pinMode(P_5,OUTPUT);
  pinMode(P_6,OUTPUT);
  pinMode(P_7,OUTPUT);
  pinMode(P_8,OUTPUT);
  pinMode(P_9,OUTPUT);
  pinMode(P_flash,OUTPUT);//flashlight transistor pin
  pinMode(P_sleep,INPUT_PULLUP);//P1.3
  pinMode(P_flaswch,INPUT_PULLUP);//P2.0
  pinMode(P_L,INPUT_PULLUP);//P1.2
  pinMode(P_R,INPUT_PULLUP);//P1.1
  P1IE |= BIT1;//enable interrupt by change in voltage at pin P1.1, P1.2 and P2.0
  P1IE |= BIT2;  
  P2IE |= BIT0;
  P1IES |= BIT1;//trigger interrupt at HIGH to LOW transition in P1.1, P1.2 and P2.0
  P1IES |= BIT2; 
  P2IES |= BIT0;            
  P1IFG &= ~BIT1;//clear interrupt flage IFG corresponding to pin P1.1, P1.2 and P2.0
  P1IFG &= ~BIT2;
  P2IFG &= ~BIT0;
} 
